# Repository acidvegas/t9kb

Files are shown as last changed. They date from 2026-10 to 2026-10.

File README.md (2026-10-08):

# T9KB

A tiny phone-style keypad for DIY projects that talks I2C. Plug it into an ESP32 *(or anything with Qwiic / I2C)* and you get the full key layout of an old desk phone handset: 3 soft keys, a 5-way d-pad, call / end / speaker / mute, and the 3x4 number pad.

There are virtually no good small modules on the market for basic I2C text input. The [M5Stack CardKB](https://docs.m5stack.com/en/unit/cardkb_1.1) is about the only one, and it is a tiny QWERTY board. Nothing like it exists for T9, so I made this one for T9 phone-style input on my own projects, starting with a DIY VoIP phone.

The layout follows the Grandstream WP826 handset. Keys are metal snap domes on gold pads, the same way real phones do it, and a 3D printed TPU key mat goes on top. A single TI TCA8418 scans the keys, so the board has no firmware to flash. The text side *(multi-tap, T9, key repeat)* lives in an Arduino library on the host.

**Status:** v0.2 hardware is designed and ready to order, not built or tested yet. The Arduino library compiles and its logic is tested on a PC, not yet on real hardware. The key mat is designed, not printed yet.

<p align="center">
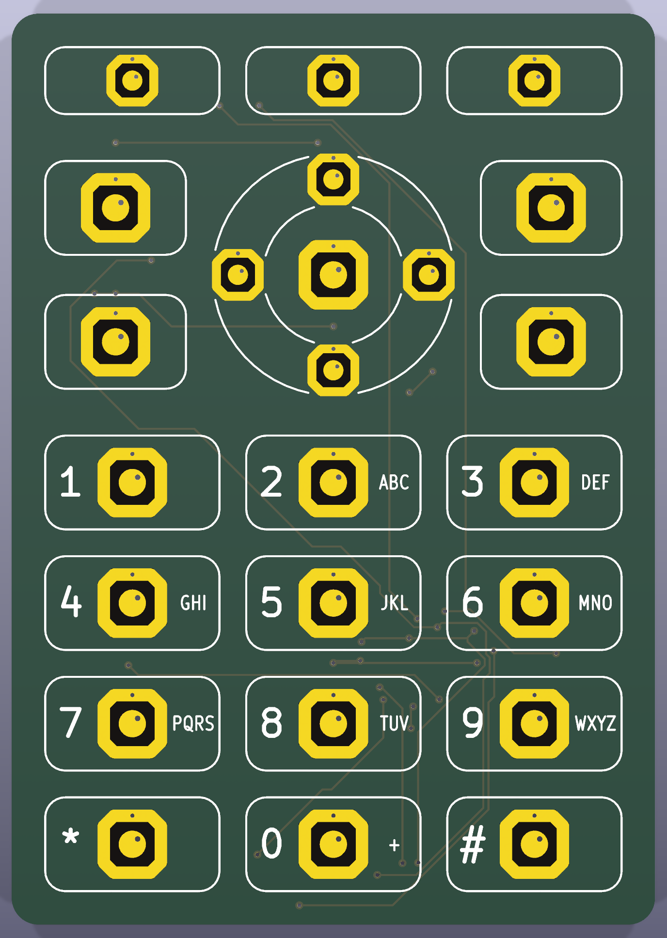
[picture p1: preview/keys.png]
Key face
  
  &nbsp;
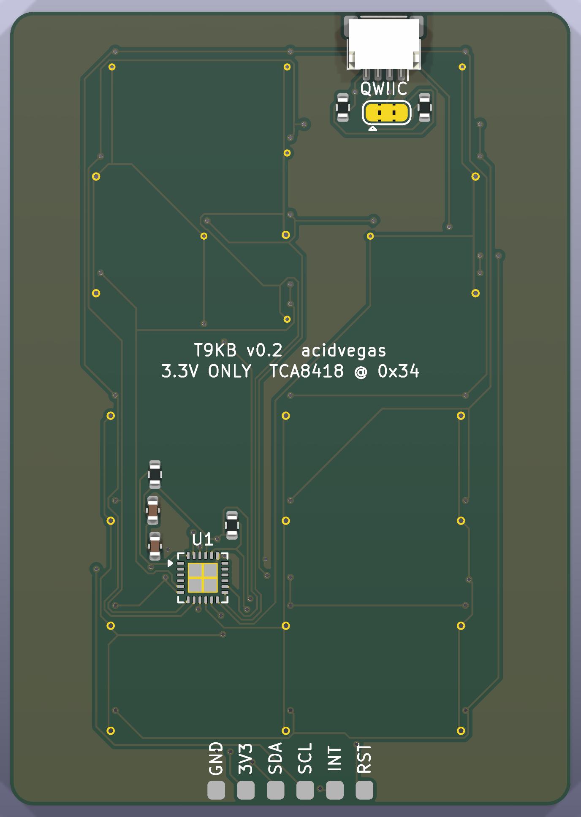
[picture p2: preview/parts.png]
Parts side
  
</p>
<p align="center">
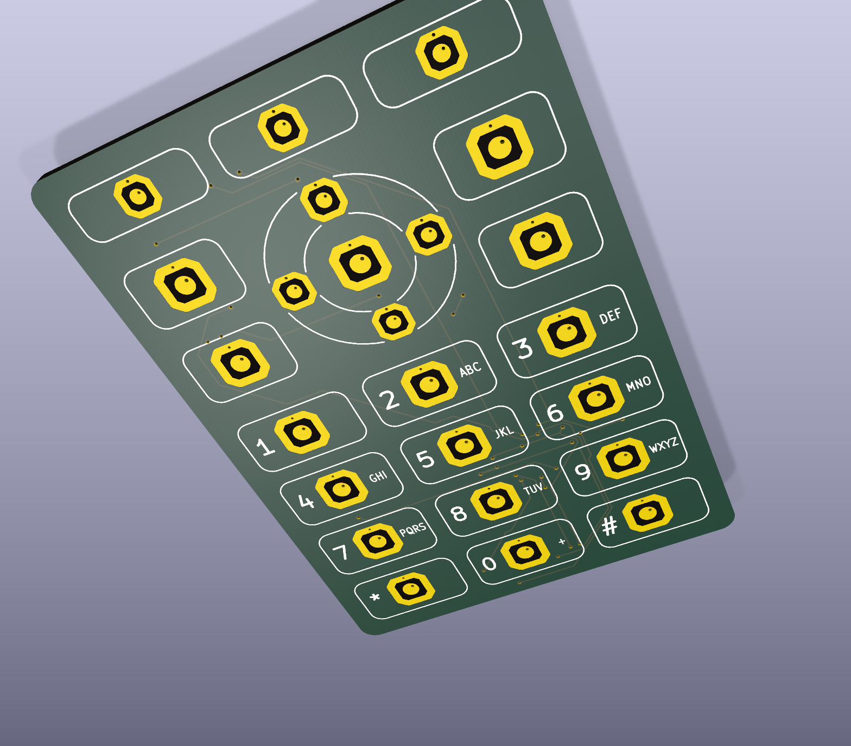
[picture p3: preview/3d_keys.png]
Key face, angled
  
  &nbsp;
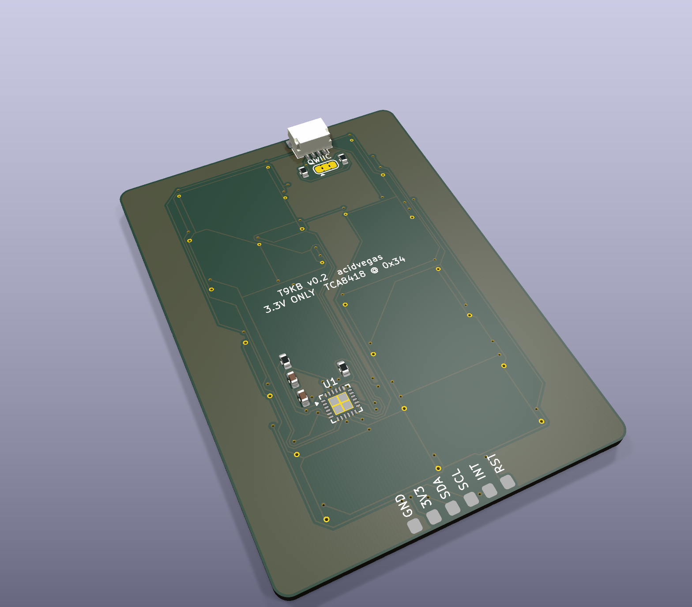
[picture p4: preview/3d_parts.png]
Parts side, angled
  
</p>

The 3D model for case and key mat design is `hardware/t9kb.step`.

## Arduino library

The library is in `library/` *(Arduino, compiles for the ESP32 core)*. Install it by copying or symlinking `library/` into your Arduino `libraries` folder as `T9KB`.

```cpp
#include <Wire.h>
#include <T9KB.h>

T9KB keypad;

void setup() {
	Wire.begin();
	keypad.begin(); // or keypad.begin(Wire, INT_GPIO, RST_GPIO) with the INT / RST pads wired
}

void loop() {
	keypad.update();
	while (keypad.available()) {
		T9Event ev = keypad.read(); // ev.key, ev.type (press / release / long / repeat), ev.code (raw key number)
	}
	uint8_t c;
	while ((c = keypad.getChar())) {
		// typed text, CardKB style
	}
}
```

Text entry through `getChar()`:

| Key | Tap in Abc / abc / ABC | Long press | 123 mode |
| --- | --- | --- | --- |
| 2 to 9 | Letters, then the digit *(abc2, def3, ... wxyz9)* | The digit  | Digit |
| 1 | `1 . , ' ? ! " -` | 1 | 1 |
| 0 | Space | 0 | 0, long press `+` |
| `*` | Symbols *(below)* | | `*` |
| `#` | `#` | Next mode  | `#`, long press mode |
| Right soft key | Backspace *(auto-repeats)* | | Backspace |
| Arrows | CardKB arrow codes *(auto-repeat)* | | Arrow codes |

The `*` symbols, in order: ``. , ' ? ! " - ( ) @ / : _ ; + % * = < > $ [ ] { } \ ~ ^ # | ` &``

- **Live preview:** each tap sends the letter right away, and the next tap on the same key sends a backspace plus the next letter. Show the text as it comes in and the screen previews every letter as you cycle. `pending()` is true while the last letter can still change, so you can underline it. The letter is final after 800 ms or when another key is pressed.
- **Modes:** long press `#` cycles Abc, abc, ABC, 123. It starts in Abc, which capitalizes the first letter and any letter after `. `, `! ` or `? `. `setMode()` changes the mode from code.
- **Codes:** backspace `0x08`, left `0xB4`, up `0xB5`, down `0xB6`, right `0xB7`, the same values the M5Stack CardKB sends. `getChar()` returns 0 when nothing is waiting.
- **Events only:** OK, call, end, the left and middle soft keys, speaker and mute type nothing. Handle them from key events.
- **Events:** read them from the queue with `available()` / `read()`, or set a callback with `onKey()`. `isPressed()` works for every key, so combos like a soft key plus a digit work.
- **Timing:** `setTapTimeout()` *(800 ms)*, `setLongPress()` *(600 ms)* and `setRepeat()` *(500 ms delay, 80 ms rate)*.
- **Reading the keypad:** without INT the library polls every 10 ms over I2C. With INT wired it only reads when a key event is waiting.

| Example | What it shows |
| --- | --- |
| `Text` | Line editor on the serial monitor with live preview and mode display |
| `Events` | Prints every key event with its raw key number |
| `Dialer` | 123 mode phone dialer using the `onKey()` callback, Call and End |
| `DeepSleep` | ESP32 deep sleep, woken by a keypress on the INT wire |

T9 word prediction is planned for later.

## Key mat

A 3D printed TPU key mat that sits on the key face: black keys with flush white legends, sized to the exact key layout. The keys stand 2.6 mm above a flat base, so the case plate can sit on the base and cover the gaps while the keys poke through. Each key is a separate island joined to the base by a thin flexible web, with a small plunger underneath that presses its dome.

<p align="center">
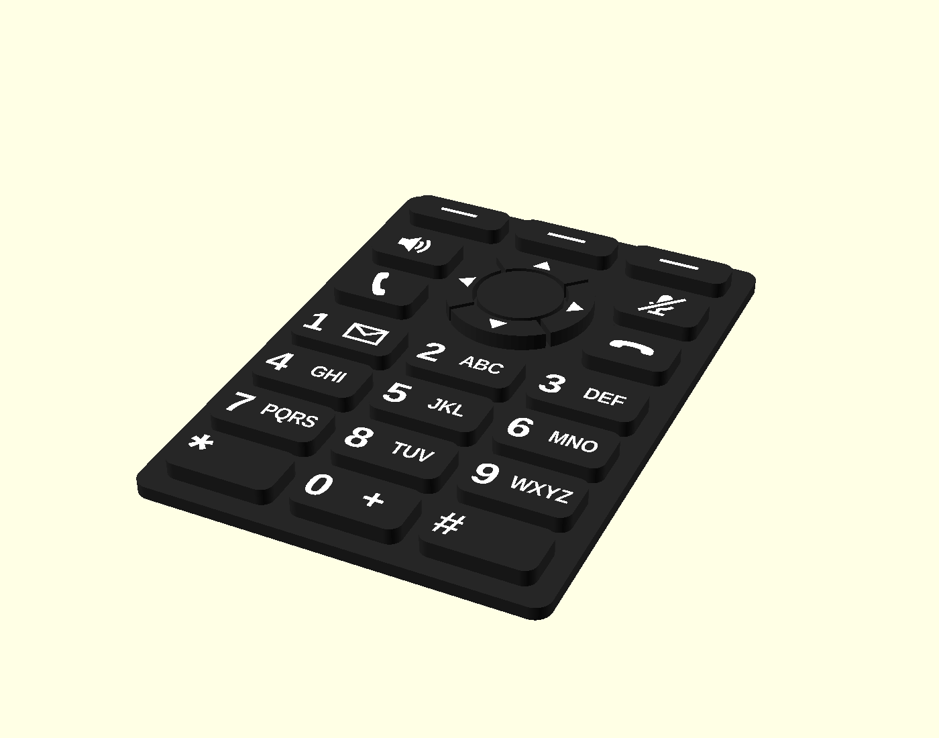
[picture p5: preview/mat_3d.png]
Key mat
  
  &nbsp;
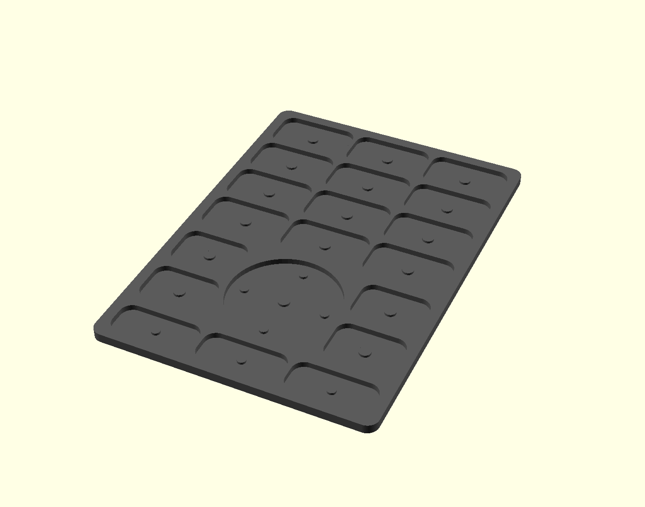
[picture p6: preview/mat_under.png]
Key mat underside
  
</p>

| File | What |
| --- | --- |
| `mat/t9kb_mat_body.stl` | Black body, already flipped face down for printing |
| `mat/t9kb_mat_legends.stl` | White legends, lined up with the body |
| `mat/t9kb_mat.scad` | OpenSCAD source with all dimensions as parameters  |

Legends: digits and letters on the number keys, an envelope *(voicemail)* on 1, speaker, muted microphone, call and hang up icons on the side keys, a line on each soft key, and arrows on the d-pad. The center select key is blank.

Printing *(Bambu A1 mini, OrcaSlicer)*:

1. Import both STLs at once and answer **yes** to loading them as a single object with multiple parts.
2. Set the body to black TPU and the legends to white TPU *(95A)*. Dry the filament first.
3. Print with 0.2 mm layers on the textured plate. The key tops print against the plate, so they come out flat and matte. Use the Arachne wall generator so the small letters *(0.3 mm strokes)* print.
4. The white is only in the first 2 layers *(0.4 mm deep)*, so every color swap happens in the first few minutes. After that the rest of the mat is black.
5. Turn on supports *(tree, on build plate only)*. Face down, the 2.5 mm border of the base hangs out past the outer keys with nothing under it. That surface ends up under the case plate, so support marks there don't show.

| Part | Size |
| --- | --- |
| Mat | 48 x 68 x 4.2 mm |
| Base | 1.6 mm thick, rests on the board; the case plate sits on it |
| Keys | Stand 2.6 mm above the base, 0.6 mm groove around each |
| Key underside | 1.0 mm above the board |
| Plungers | 2.0 mm wide on 5 mm domes, 1.5 mm on 4 mm domes |
| Legends | 0.4 mm deep, flush |

`RAISE` *(key height above the base)* in `t9kb_mat.scad` should be your case plate thickness plus how far you want the keys to stick out. The plungers stop 0.1 mm above the domes, set by `DOME_H = 0.5` *(dome height including adhesive)*. Measure your domes once they arrive. If the keys feel pre-pressed or dead, change `DOME_H` and re-export:

```
cd mat
openscad -D 'PART="body"' -D PRINT=true -o t9kb_mat_body.stl t9kb_mat.scad
openscad -D 'PART="legends"' -D PRINT=true -o t9kb_mat_legends.stl t9kb_mat.scad
```

## Case

A 3D printed two-part case: a top shell with a hole for every key and a back lid that snaps in. The mat and board drop into the top shell face down, then the lid snaps in and clamps the stack together. No screws, and the board needs no mounting holes.

<p align="center">
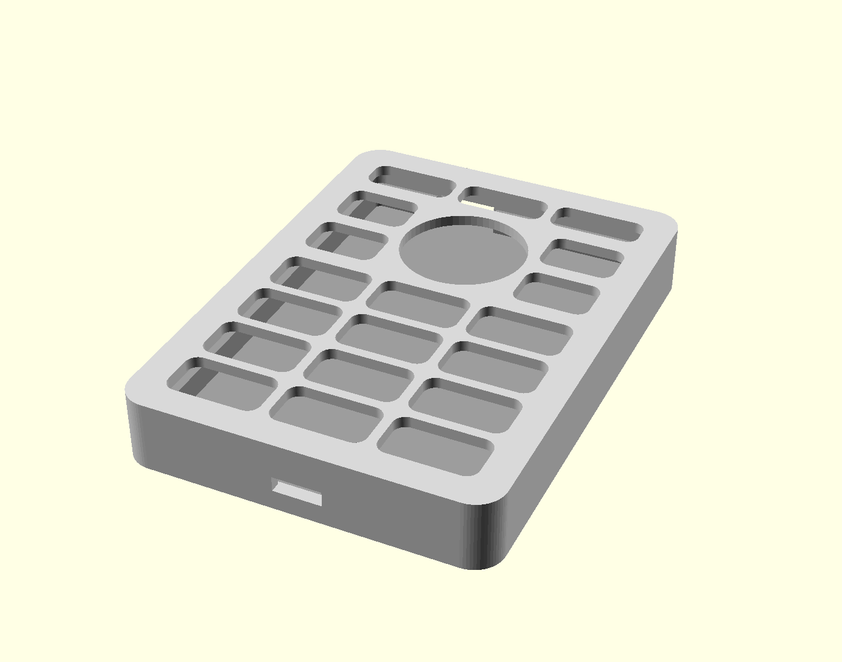
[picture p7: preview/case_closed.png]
Case
  
  &nbsp;
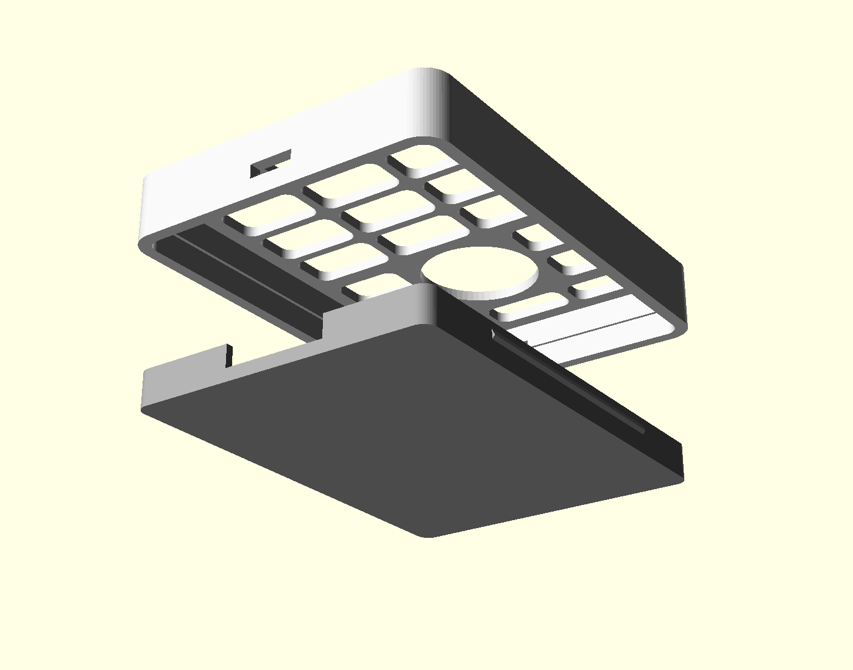
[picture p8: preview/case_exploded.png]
Case top and lid
  
</p>
<p align="center">
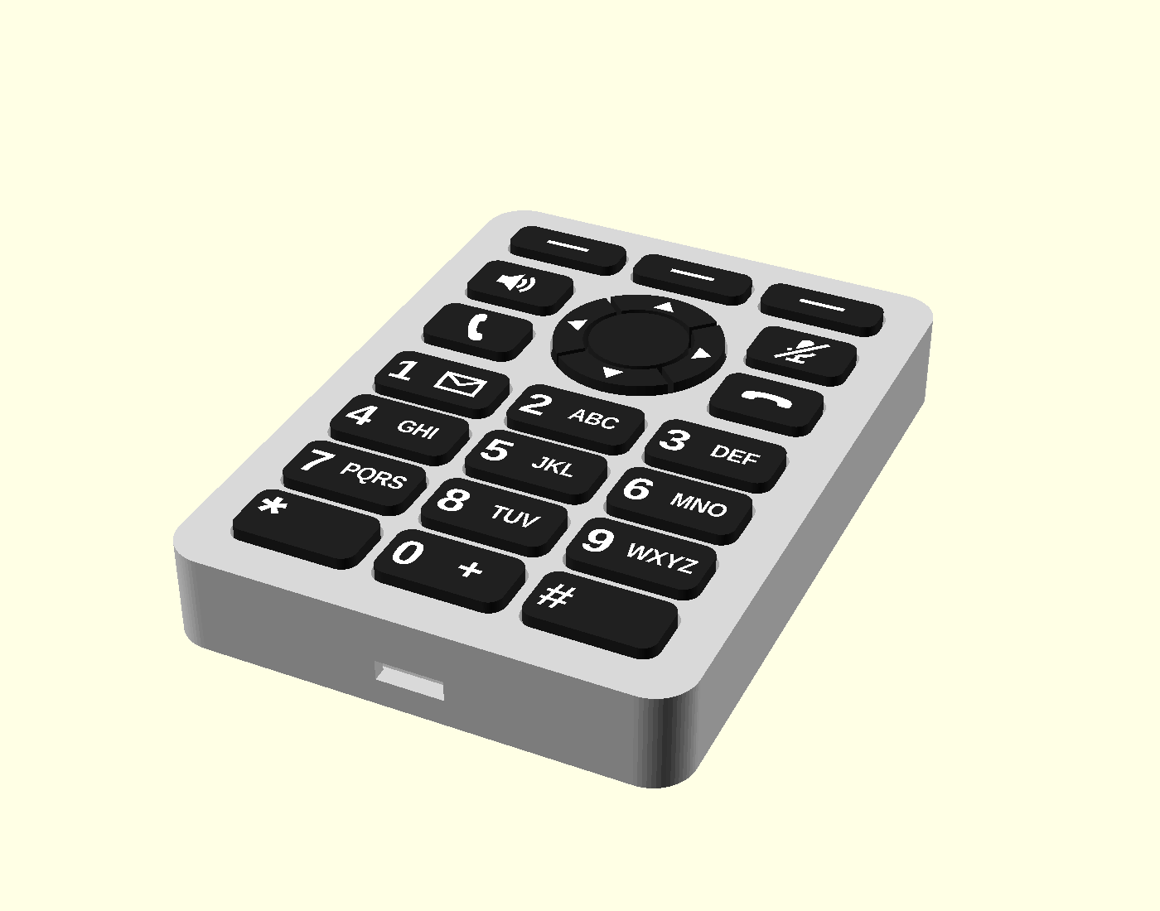
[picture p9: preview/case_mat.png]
Case with the key mat
  
</p>
<p align="center">
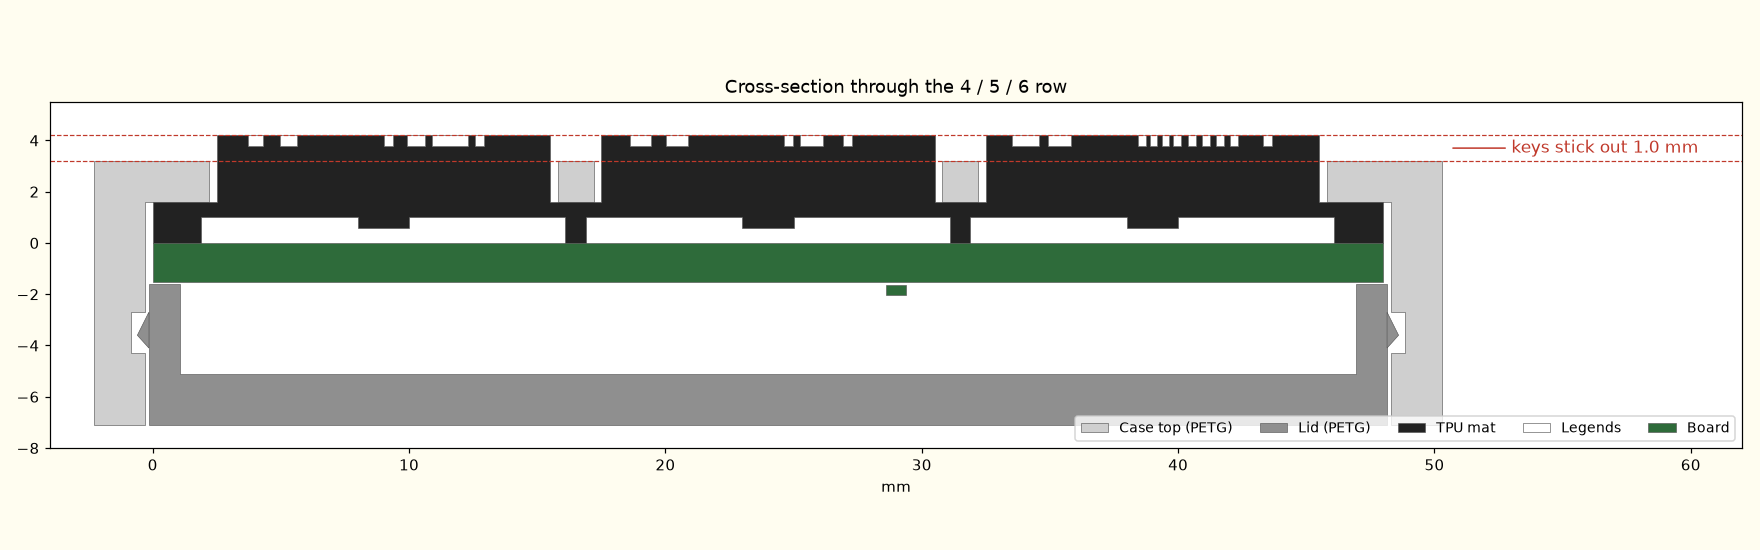
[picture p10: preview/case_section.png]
Cross-section
  
</p>

| File | What |
| --- | --- |
| `case/t9kb_case_top.stl` | Top shell, already flipped plate down for printing |
| `case/t9kb_case_lid.stl` | Back lid, floor down |
| `case/t9kb_case.scad` | OpenSCAD source with all dimensions as parameters  |

| Part | Size |
| --- | --- |
| Outside | 52.6 x 72.6 x 10.3 mm |
| Walls | 2.0 mm |
| Top plate | 1.6 mm, sits on the mat base; keys stick out 1.0 mm |
| Key holes | 0.3 mm clearance around each key, one round hole for the d-pad |
| Lid | 2.0 mm floor, 1.2 mm skirt that holds the board against the mat |
| Snap | 0.45 mm bead on each long side of the lid skirt, catches 0.3 mm in a groove |
| Openings  | Qwiic slot on the top edge, wire hole on the bottom edge for the J2 pads |
| Inside | 3.5 mm under the board for the parts *(tallest is the Qwiic jack, 2.96 mm)* |

Print both parts in PETG. It bends instead of cracking, which matters for the snap. 0.2 mm layers, 3 walls, no supports needed. The top shell prints plate down, so the face comes out flat.

Assembly:

1. Put the key mat face down into the top shell so every key sits in its hole.
2. Stick the domes on the board, then lay the board key face down onto the mat.
3. Feed any J2 wires out through the bottom hole.
4. Press the lid in from the back until both long sides click.

To open it, pry the lid out at the Qwiic slot.

## Specs

| Item | Value |
| --- | --- |
| Board size  | 48 x 68 mm, 1.6 mm thick, 2 layers, 2 mm corner radius |
| Keys | 24 metal dome pads *(Snaptron patterns: 17 for 5 / 5.3 mm domes, 7 for 4 mm domes)* |
| Controller  | TI TCA8418 keypad scanner, no firmware |
| I2C address | 0x34 *(fixed)* |
| Power | 3.3 V only *(1.65 to 3.6 V)* |
| Connector | Qwiic / STEMMA QT *(JST SH 4-pin)*, top edge, parts side |
| Key face | Flat: gold dome pads and legends only *(KiCad bottom layer)* |
| Parts side  | All parts *(8 total, KiCad top layer)* |

## Key layout

All sizes in mm, measured on the key face. The key area is 43 x 63, centered on the board with a 2.5 border on every side.

| Keys | Count | Size | Dome |
| --- | ----- | --- | ---- |
| Soft keys | 3 | 13 x 5 | 4 mm |
| D-pad ring | | 18 circle | |
| D-pad center | 1 | 10.5 circle | 5 mm |
| D-pad arrows | 4 | In the ring around the center | 4 mm |
| Side keys | 4 | 10.5 x 7, two on each side | 5 mm |
| Number keys  | 12 | 13 x 7 | 5 mm |

| Gap | Size |
| --- | ---- |
| Between soft keys, between number keys | 2 |
| Soft keys to d-pad | 3 |
| Soft keys to side keys | 3.5  |
| Between the 2 stacked side keys | 3 |
| D-pad to number keys | 3 |
| Side keys to number keys | 3.5  |

The outer edges of the soft keys, side keys and number keys all line up.

## Connections

Qwiic connector *(J1)*:

| Pin | Signal |
| --- | --- |
| 1 | GND |
| 2 | 3.3V |
| 3 | SDA |
| 4 | SCL |

Breakout pads on the bottom edge of the parts side *(J2, 2.54 mm pitch, solder wires or an SMD header)*:

| Pad | Signal | Notes |
| --- | --- | --- |
| 1 | GND | |
| 2 | 3V3 | |
| 3 | SDA | |
| 4 | SCL | |
| 5 | INT | Goes low when a key event is waiting *(10k pull-up on board)* |
| 6 | RST | Pull low to reset the TCA8418 *(10k pull-up on board)* |

Qwiic has no spare wire for INT. Over Qwiic alone the host polls the keypad; solder a wire from J2's INT pad to a GPIO for interrupt-driven reads and wake-on-keypress.

The board has 4.7k I2C pull-ups through the 3-pad solder jumper JP1. It comes bridged. If you chain it with other boards that already have pull-ups, cut both copper bars on JP1.

## Key map

The TCA8418 reports a key number from 1 to 80 *(`row * 10 + column + 1`)*. Bit 7 of the event byte is 1 for press, 0 for release.

| Key | Row | Col | Key number |
| --- | --- | --- | --- |
| 1 | 0 | 0 | 1 |
| 2 | 0 | 1 | 2 |
| 3 | 0 | 2 | 3 |
| Soft left | 0 | 3 | 4 |
| Soft middle | 0 | 4 | 5 |
| Soft right  | 0 | 5 | 6 |
| 4 | 1 | 0 | 11 |
| 5 | 1 | 1 | 12 |
| 6 | 1 | 2 | 13 |
| Speaker | 1 | 3 | 14 |
| Up | 1 | 4 | 15 |
| Mute | 1 | 5 | 16 |
| 7 | 2 | 0 | 21 |
| 8 | 2 | 1 | 22 |
| 9 | 2 | 2 | 23 |
| Left | 2 | 3 | 24 |
| OK | 2 | 4 | 25 |
| Right | 2 | 5 | 26 |
| * | 3 | 0 | 31 |
| 0 | 3 | 1 | 32 |
| # | 3 | 2 | 33 |
| Call | 3 | 3 | 34 |
| Down | 3 | 4 | 35 |
| End | 3 | 5 | 36 |

Minimum setup over I2C:

| Register | Name | Write | Why |
| --- | --- | ----- | --- |
| 0x1D | KP_GPIO1 | 0x0F  | Rows 0 to 3 are keypad rows |
| 0x1E | KP_GPIO2 | 0x3F  | Columns 0 to 5 are keypad columns |
| 0x01 | CFG | 0x01  | Interrupt on key events |

Then read `KEY_LCK_EC` *(0x03)* for the event count, read `KEY_EVENT_A` *(0x04)* once per event, and write 0x01 to `INT_STAT` *(0x02)* to clear the interrupt.

The board has no diodes, so single keys and 2-key combos are reliable. Pressing 3 keys that form an L in the matrix can show a fake 4th key.

## Parts

Assembled by JLCPCB *(all on the parts side)*:

| Ref | Part | Package | LCSC | JLC type |
| --- | --- | --- | --- | --- |
| U1 | TCA8418RTWR | WQFN-24 4x4 mm  | C138713 | Extended |
| J1 | JST SM04B-SRSS-TB *(Qwiic)* | SMD right angle | C160404 | Extended |
| C1 | 100 nF | 0603 | C14663  | Basic |
| C2 | 10 uF | 0603 | C19702  | Basic |
| R1, R2 | 4.7k *(I2C pull-ups)* | 0603 | C23162  | Basic |
| R3, R4 | 10k *(RST, INT pull-ups)* | 0603 | C25804  | Basic |

Bought separately and added by hand:

| Qty | Part | Where | Notes |
| --- | --- | --- | --- |
| 20  | 5 to 5.3 mm metal domes *(see Dome sources)* | Varies | 17 needed, rest are spares |
| 10  | 4 mm metal domes *(see Dome sources)* | Varies | 7 needed, rest are spares  |
| 1 | Kapton *(polyimide)* tape | Anywhere | Only for loose domes |

## Dome sources

The pads follow Snaptron's published single-sided contact patterns: 17 pads for 5 / 5.3 mm domes and 7 pads for 4 mm domes *(soft keys and d-pad arrows)*. Prices and stock were checked on 2026-10-07.

Recommended, exact match for the pad patterns with a known force:

| Pads | Part | Source | Force | Price | Notes |
| ---- | --- | --- | --- | --- | --- |
| 5 mm | Snaptron GX05170 *(5.3 mm four-leg)* | [DigiKey 4955-GX05170-ND](https://www.digikey.com/en/products/detail/snaptron/GX05170/20376517) | 170 g ±30 g | $36.37 for 100 | Loose, needs tape |
| 4 mm | Snaptron GX04200 *(4.0 mm four-leg)* | [DigiKey 4955-GX04200-ND](https://www.digikey.com/en/products/detail/snaptron/GX04200/20376515) | 200 g ±30 g | $37.99 for 100 | Loose, needs tape |
| Tape | 1" polyimide *(Kapton style)* tape | [Amazon B006ZFNB2I](https://www.amazon.com/Mil-Kapton-Tape-Polyimide-yds/dp/B006ZFNB2I) | | | |

Cheaper, peel-and-stick, from [ButtonWorx](https://buttonworx.com) *(Maine, US, $4 minimum order, no force listed)*:

| Pads | Part | Price | Fit |
| ---- | --- | --- | --- |
| 5 mm | [Snap Dome Round 5mm Dimple, Peel and Stick option](https://buttonworx.com/metal-domes/285-snap-dome-round-5mmD.html) | $0.80 each | Whole rim on the frame |
| 5 mm | [Snap Dome Chopped Circle 5.2mm Peel & Stick](https://buttonworx.com/metal-domes/291-snap-dome-cut-circle-5-2x3-8.html) | $0.50 each | Fits |
| 4 mm | [Snap Dome Round 4mm Dimple, Peel and Stick option](https://buttonworx.com/metal-domes/284-snap-dome-round-4mmD.html) | $0.80 each | Marginal: rim rests on the frame corners only, no size tolerance given |

The adhesive squares around neighboring d-pad domes may overlap; trim them if they do. A 4.5 mm dome does not fit the 4 mm pads.

## Ordering from JLCPCB

Upload `hardware/fab/t9kb_gerbers.zip` and use these settings:

| Setting | Value |
| --- | --- |
| Layers | 2 |
| Dimensions | 48 x 68 mm *(auto-detected)* |
| Material | FR-4 |
| PCB thickness  | 1.6 mm *(Economic PCBA only offers ENIG at 1.6 mm)* |
| Surface finish | ENIG *(required, the dome contacts need gold)* |
| Gold thickness | 2U" *(1U" also works)* |
| PCB assembly | Yes, Economic |
| Assembly side  | Top side |
| BOM / CPL | `hardware/fab/BOM.csv` and `hardware/fab/CPL.csv` |

On the placement preview page, check these before paying:

- **U1:** the dot on the chip lines up with the pin 1 triangle printed on the board.
- **J1:** the connector opening faces the top edge of the board.

If either is turned wrong, rotate it right there in the preview. Resistors and capacitors do not care.

## Assembly

1. Clean the key face with isopropyl alcohol.
2. Place a dome on each gold pad, centered on the round contact *(not on the small hole, which is off-center on purpose)*. The small pads *(soft keys and d-pad arrows)* take 4 mm domes, the rest take 5 mm domes. Four-leg domes go with a leg on each of the 4 cut corners of the gold frame.
3. Tape over the domes with Kapton tape, or use peel-and-stick domes. Air vents through the small hole in each center pad, so the tape can cover the domes fully.
4. Test by pressing each dome with a finger while reading key events.

A dome that sits crooked can be peeled off and placed again. Nothing on the key face is soldered.

## Rebuilding the board

The board is generated by script *(KiCad 9)*. There is no schematic; the netlist lives in `gen_pcb.py`.

```
cd hardware
./autoroute.sh    # place parts, autoroute with freerouting, pour ground, run DRC
python3 fab.py    # gerbers, drill files, BOM, CPL
```

`autoroute.sh` expects `freerouting.jar` in `tools/`. Download it from the [freerouting v2.0.1 release](https://github.com/freerouting/freerouting/releases/tag/v2.0.1) *(needs Java 21)*.

## References

- `ref/tca8418.pdf`: [TI TCA8418 datasheet](https://www.ti.com/lit/ds/symlink/tca8418.pdf)
- `ref/snaptron_guide.pdf`: Snaptron metal dome design guide *(contact pad patterns, plating, venting)*

## Notes

- The TCA8418 exposed pad is tied to ground, as TI recommends *(ground or floating, never power)*.
- Dome pads follow Snaptron's single-sided contact patterns for 5 / 5.3 mm and 4 mm domes, with the off-center via-in-pad option for 2-layer boards. There is no solder mask inside the pad area, per Snaptron.
- U1 uses TI's own land pattern and stencil for the RTW0024B package *(TCA8418 datasheet)*.
- The key face is the KiCad bottom layer so JLC assembles the top side.
- LEDs and backlight were removed for this revision. They may come back later.

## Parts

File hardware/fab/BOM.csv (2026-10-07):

Comment | Designator | Footprint | LCSC
100nF | C1 | C_0603_1608Metric | C14663
10k | R3,R4 | R_0603_1608Metric | C25804
10uF | C2 | C_0603_1608Metric | C19702
4.7k | R1,R2 | R_0603_1608Metric | C23162
Qwiic | J1 | JST_SH_SM04B-SRSS-TB_1x04-1MP_P1.00mm_Horizontal | C160404
TCA8418RTWR | U1 | WQFN-24-1EP_4x4mm_P0.5mm_EP2.45mm_TI_RTW0024B | C138713

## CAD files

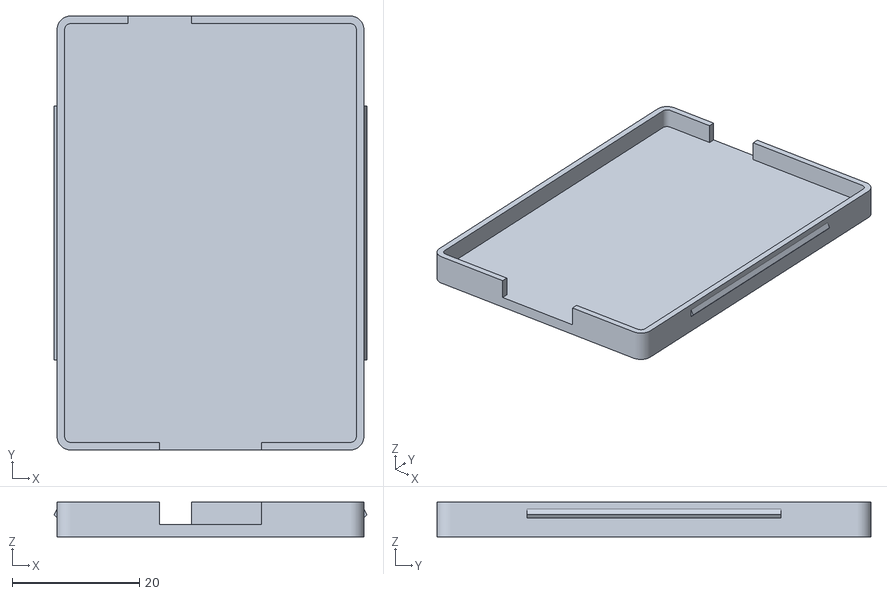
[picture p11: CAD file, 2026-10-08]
case/t9kb_case_lid.stl
49.2 x 68.3 x 5.50

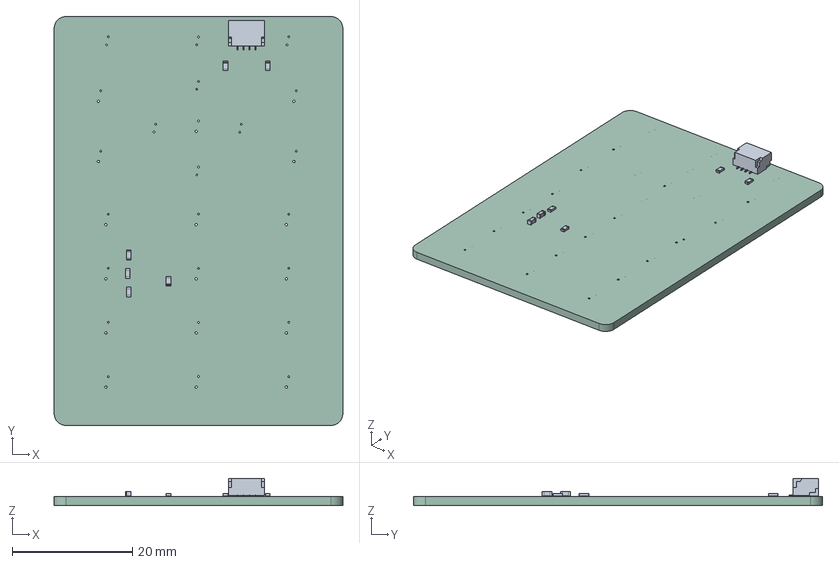
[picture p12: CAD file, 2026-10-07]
hardware/t9kb.step
48.0 x 68.0 x 4.55 mm
C_0603_1608Metric x 2
R_0603_1608Metric x 4
JST_SH_SM04B-SRSS-TB_1x04-1MP_P1.00mm_Horizontal
t9_keypad_back_PCB

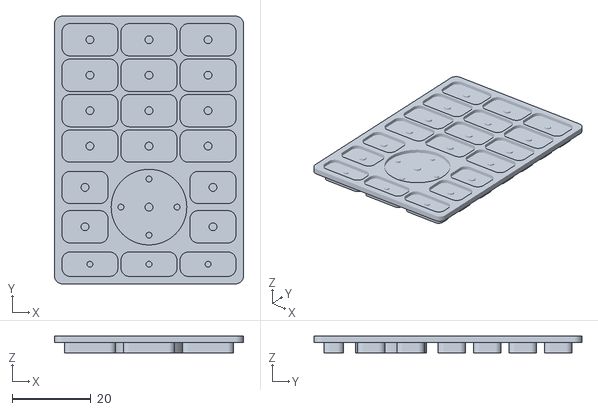
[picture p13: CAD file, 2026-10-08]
mat/t9kb_mat_body.stl
48.0 x 68.0 x 4.20

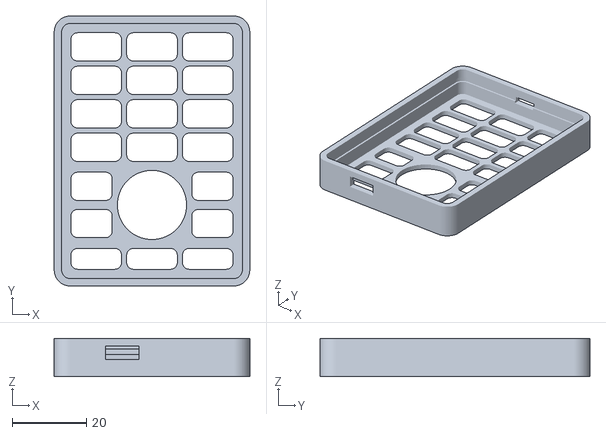
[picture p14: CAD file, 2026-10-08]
case/t9kb_case_top.stl
52.6 x 72.6 x 10.3

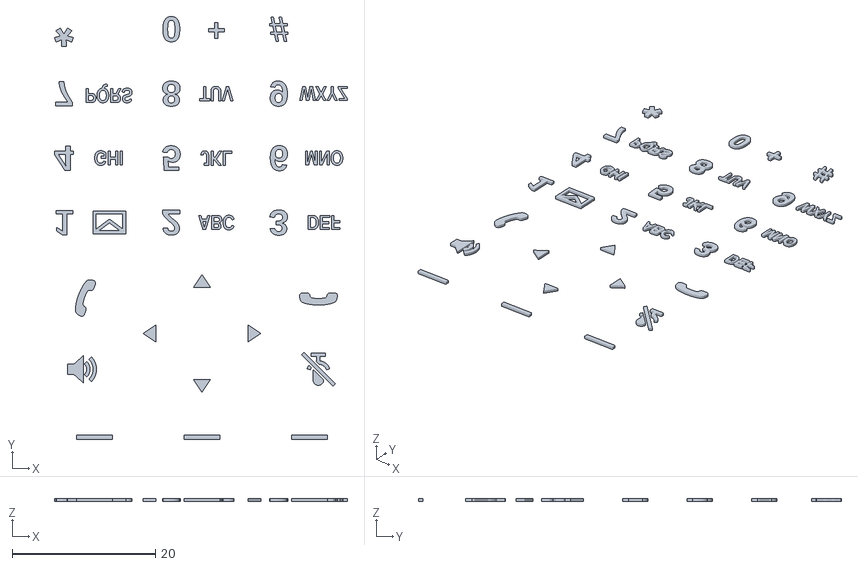
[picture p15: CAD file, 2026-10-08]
mat/t9kb_mat_legends.stl
40.9 x 59.0 x 0.4

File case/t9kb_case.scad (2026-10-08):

// T9KB case: top shell with key cutouts + snap-in back lid. PETG recommended.
// The board and key mat drop into the top shell face down, then the lid snaps in and clamps them.
// Coordinates follow the board's key face: x right, y down from the top left corner, z = 0 at the key face.
// Export: openscad -D 'PART="top"' / "lid", PRINT=true lays each part flat for printing.

use <../mat/t9kb_mat.scad>

PART  = "case";  // top, lid, case (both, closed)
PRINT = false;

W = 48;          // board
H = 68;
R = 2;

CLR    = 0.3;    // board / mat to wall
WALL   = 2.0;    // side walls
PLATE  = 1.6;    // top plate over the mat base
MAT    = 1.6;    // mat base thickness (mat BEZEL)
KEYCLR = 0.3;    // key cutout clearance
PCB    = 1.6;
BACK   = 3.5;    // room under the board for the parts (tallest is the Qwiic jack, 2.96 mm)
FLOOR  = 2.0;    // lid thickness
LIDCLR = 0.15;   // lid to wall
SKIRT  = 1.2;    // lid skirt thickness, also the ledge the board rests on
BEAD   = 0.45;   // snap bead on the lid skirt, catches 0.3 mm past the 0.15 mm lid gap
BEAD_Z = -3.6;   // snap height

Z_TOP   = MAT + PLATE;             // 3.2
Z_BOARD = -PCB;                    // -1.6, parts side of the board
Z_IN    = Z_BOARD - BACK;          // -5.1, top of the lid
Z_BOT   = Z_IN - FLOOR;            // -7.1

QWIIC_X = 16;    // Qwiic jack center on the top edge (key face x)
WIRE_X  = 24;    // breakout pads center on the bottom edge

$fn = 64;

module board2d(d = 0) {
	offset(R + d) offset(-R) square([W, H]);
}

module ring(d0, d1) {
	difference() {
		board2d(d1);
		board2d(d0);
	}
}

// key-face y to OpenSCAD y
function Y(y) = H - y;

module bead(len) {
	// lead-in on top (the lid goes in from below), steeper retaining face underneath
	rotate([90, 0, 0]) linear_extrude(len, center = true) polygon([[0, -0.5], [BEAD, 0], [0, 0.9]]);
}

module top() {
	difference() {
		union() {
			// plate
			translate([0, 0, MAT]) linear_extrude(PLATE) board2d(CLR + WALL);
			// walls
			translate([0, 0, Z_BOT]) linear_extrude(Z_TOP - Z_BOT) ring(CLR, CLR + WALL);
		}
		// key holes
		translate([0, 0, MAT - 0.01]) linear_extrude(PLATE + 0.02) keys2d(KEYCLR);
		// snap groove for the lid bead
		translate([0, 0, BEAD_Z - 0.7]) linear_extrude(1.6) ring(CLR - 0.01, CLR + BEAD + 0.1);
		// Qwiic slot
		translate([QWIIC_X - 4.5, H - 0.5, Z_BOARD - 3.4]) cube([9, CLR + WALL + 1.5, 3.6]);
		// wire hole
		translate([WIRE_X - 3.5, -CLR - WALL - 1, Z_BOARD - 2.6]) cube([7, CLR + WALL + 1.5, 2.2]);
	}
}

module lid() {
	difference() {
		union() {
			translate([0, 0, Z_BOT]) linear_extrude(FLOOR) board2d(CLR - LIDCLR);
			// skirt: rises to the board and holds it against the mat
			translate([0, 0, Z_IN - 0.01]) linear_extrude(BACK + 0.01) ring(CLR - LIDCLR - SKIRT, CLR - LIDCLR);
			// snap beads on the long sides, clear of the corners
			for (x = [-CLR + LIDCLR, W + CLR - LIDCLR]) translate([x, H / 2, BEAD_Z]) rotate([0, 0, x < W / 2 ? 180 : 0]) bead(40);
		}
		// clear the Qwiic jack and its plug
		translate([QWIIC_X - 5, Y(5), Z_IN]) cube([10, 10, BACK + 1]);
		// clear the breakout pads and their wires
		translate([WIRE_X - 8, Y(H + 5), Z_IN]) cube([16, 7, BACK + 1]);
	}
}

if (PART == "top") {
	if (PRINT) translate([0, H, Z_TOP]) rotate([180, 0, 0]) top();
	else color("#d0d0d0") top();
}
if (PART == "lid") {
	if (PRINT) translate([0, 0, -Z_BOT]) lid();
	else color("#9a9a9a") lid();
}
if (PART == "case") {
	color("#d0d0d0") top();
	color("#9a9a9a") lid();
}

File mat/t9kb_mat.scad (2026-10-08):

// T9KB TPU key mat: black body with flush white legends, sized to the T9KB board (48 x 68 mm).
// Coordinates follow the board's key face: x right, y down from the top left corner.
// Export: openscad -D 'PART="body"' / "legends" / "both", PRINT=true flips it face down for printing.

PART  = "both";  // body, legends, both (preview)
PRINT = false;   // true: key tops on the bed, for the print files

W = 48;          // board size
H = 68;
R = 2;           // board corner radius

BEZEL  = 1.6;    // flat part between the keys, rests on the board; the case plate sits on it
RAISE  = 2.6;    // how far the keys stand above the flat part: case plate 1.6 + 1.0 sticking out
Z0     = 1.0;    // underside of the keys above the board
WEB    = 0.6;    // flexible web joining each key to the flat part
GROOVE = 0.6;    // gap around each key
LEGEND = 0.4;    // legend depth, 2 layers at 0.2 mm

DOME_H = 0.5;    // dome height on the board incl. adhesive, measure yours
GAP    = 0.1;    // plunger clearance above the dome

KEY_R = 1.5;     // key corner radius
TOP   = BEZEL + RAISE;

DIGIT  = "Liberation Sans:style=Bold";
LETTER = "Liberation Sans Narrow:style=Bold";
ICONS  = "FreeSerif";

// x, y, w, h, legend, sublegend, dome size. Legends starting with @ are icons.
KEYS = [
	[9,     5,    13,   5, "@soft",    "",      4],
	[24,    5,    13,   5, "@soft",    "",      4],
	[39,    5,    13,   5, "@soft",    "",      4],
	[7.75,  14.5, 10.5, 7, "@speaker", "",      5],
	[40.25, 14.5, 10.5, 7, "@mute",    "",      5],
	[7.75,  24.5, 10.5, 7, "@call",    "",      5],
	[40.25, 24.5, 10.5, 7, "@end",     "",      5],
	[9,  35, 13, 7, "1", "@mail", 5], [24, 35, 13, 7, "2", "ABC", 5], [39, 35, 13, 7, "3", "DEF",  5],
	[9,  44, 13, 7, "4", "GHI",   5], [24, 44, 13, 7, "5", "JKL", 5], [39, 44, 13, 7, "6", "MNO",  5],
	[9,  53, 13, 7, "7", "PQRS",  5], [24, 53, 13, 7, "8", "TUV", 5], [39, 53, 13, 7, "9", "WXYZ", 5],
	[9,  62, 13, 7, "*", "",      5], [24, 62, 13, 7, "0", "+",   5], [39, 62, 13, 7, "#", "",     5],
];

// d-pad: 18 mm ring, 10.5 mm round center, arrow domes centered in the ring
DX = 24;
DY = 19.5;
DR = 9;
DC = 5.25;
DA = (DC + DR) / 2;

$fn = 64;

function Y(y) = H - y;

module rrect(cx, cy, w, h, r) {
	translate([cx, Y(cy)]) offset(r) square([w - 2 * r, h - 2 * r], center = true);
}

module outline() {
	offset(R) offset(-R) square([W, H]);
}

// every key shape, grown by d
module keys2d(d = 0) {
	for (k = KEYS) offset(d) rrect(k[0], k[1], k[2], k[3], KEY_R);
	translate([DX, Y(DY)]) circle(DR + d);
}

// the separate moving parts: rectangle keys, d-pad center, 4 arrows
module islands2d() {
	for (k = KEYS) rrect(k[0], k[1], k[2], k[3], KEY_R);
	translate([DX, Y(DY)]) {
		circle(DC);
		difference() {
			circle(DR);
			circle(DC + GROOVE);
			for (a = [45, 135]) rotate(a) square([2 * DR + 2, GROOVE], center = true);
		}
	}
}

// dome centers and plunger diameters
DOMES = concat(
	[for (k = KEYS) [k[0], k[1], k[6] == 5 ? 2.0 : 1.5]],
	[[DX, DY, 2.0]],
	[for (a = [0, 90, 180, 270]) [DX + DA * cos(a), DY - DA * sin(a), 1.5]]
);

// --- icons, about 5 mm, strokes 0.45 mm or more for a 0.4 mm nozzle ---

module arc2d(r1, r2, a0, a1) {
	polygon(concat([for (a = [a0:5:a1]) r2 * [cos(a), sin(a)]], [for (a = [a1:-5:a0]) r1 * [cos(a), sin(a)]]));
}

module bar(p1, p2, w = 0.5) {
	hull() {
		translate(p1) circle(d = w, $fn = 16);
		translate(p2) circle(d = w, $fn = 16);
	}
}

module speaker() {
	translate([-0.9, 0]) {
		translate([-1.6, -0.75]) square([0.9, 1.5]);
		polygon([[-0.7, -0.75], [0.6, -1.9], [0.6, 1.9], [-0.7, 0.75]]);
		arc2d(1.05, 1.55, -45, 45);
		arc2d(1.95, 2.45, -45, 45);
	}
}

module mic() {
	hull() {
		translate([0, 1.5]) circle(0.75);
		translate([0, 0.3]) circle(0.75);
	}
	translate([0, 0.5]) arc2d(1.2, 1.7, 200, 340);
	translate([-0.25, -1.9]) square([0.5, 0.8]);
	translate([-1.0, -2.3]) square([2.0, 0.5]);
}

module mute() {
	difference() {
		mic();
		rotate(-45) square([1.1, 7], center = true);
	}
	rotate(-45) square([0.5, 6.2], center = true);
}

module handset() {
	offset(0.12) text("\U01F4DE", 5.6, ICONS, halign = "center", valign = "center");
}

module mail() {
	difference() {
		square([4.6, 3.2], center = true);
		square([3.7, 2.3], center = true);
	}
	bar([-2.0, 1.3], [0, -0.2], 0.45);
	bar([2.0, 1.3], [0, -0.2], 0.45);
}

module icon(name) {
	if (name == "@soft") square([5, 0.6], center = true);
	else if (name == "@speaker") speaker();
	else if (name == "@mute") mute();
	else if (name == "@call") handset();
	else if (name == "@end") rotate(-110) handset();
	else if (name == "@mail") mail();
}

module legends2d() {
	for (k = KEYS) translate([k[0], Y(k[1])]) {
		if (k[4][0] == "@") icon(k[4]);
		else translate([-4.3, 0]) text(k[4], k[4] == "*" ? 5 : 3.6, DIGIT, halign = "center", valign = "center");
		if (k[5] == "@mail") translate([2.1, 0]) icon(k[5]);
		else if (k[5] == "+") translate([2.0, 0]) text(k[5], 3.2, DIGIT, halign = "center", valign = "center");
		else if (k[5] != "") translate([2.0, 0]) text(k[5], 2.1, LETTER, halign = "center", valign = "center");
	}
	// arrows; the center select key has no legend
	translate([DX, Y(DY)]) for (a = [0, 90, 180, 270]) rotate(a) translate([DA, 0]) polygon([[1.1, 0], [-0.7, 1.2], [-0.7, -1.2]]);
}

module legends() {
	translate([0, 0, TOP - LEGEND]) linear_extrude(LEGEND) intersection() {
		legends2d();
		islands2d();
	}
}

module body() {
	difference() {
		union() {
			// flat part between the keys
			linear_extrude(BEZEL) difference() {
				outline();
				keys2d(GROOVE);
			}
			// keys
			translate([0, 0, Z0]) linear_extrude(TOP - Z0) islands2d();
			// web across the grooves, level with the key undersides
			translate([0, 0, Z0]) linear_extrude(WEB) difference() {
				keys2d(GROOVE);
				islands2d();
			}
			// plungers
			for (d = DOMES) translate([d[0], Y(d[1]), DOME_H + GAP]) cylinder(d = d[2], h = Z0 - DOME_H - GAP + 0.01);
		}
		legends();
	}
}

module part() {
	if (PART == "body" || PART == "both") color("#303030") body();
	if (PART == "legends" || PART == "both") color("white") translate([0, 0, PART == "both" ? 0.01 : 0]) legends(); // lifted in previews to avoid z-fighting
}

if (PRINT) translate([0, H, TOP]) rotate([180, 0, 0]) part();
else part();

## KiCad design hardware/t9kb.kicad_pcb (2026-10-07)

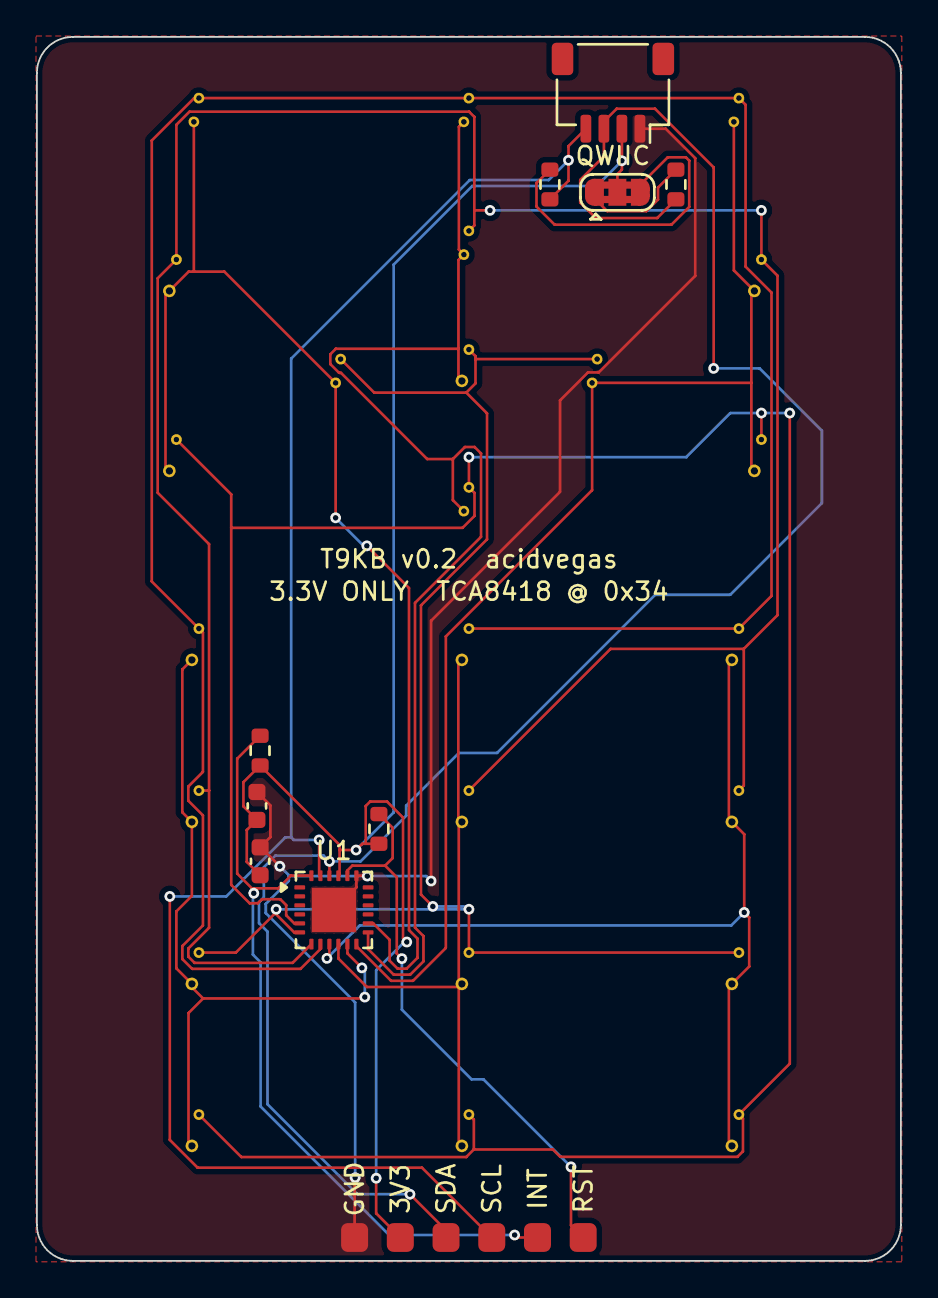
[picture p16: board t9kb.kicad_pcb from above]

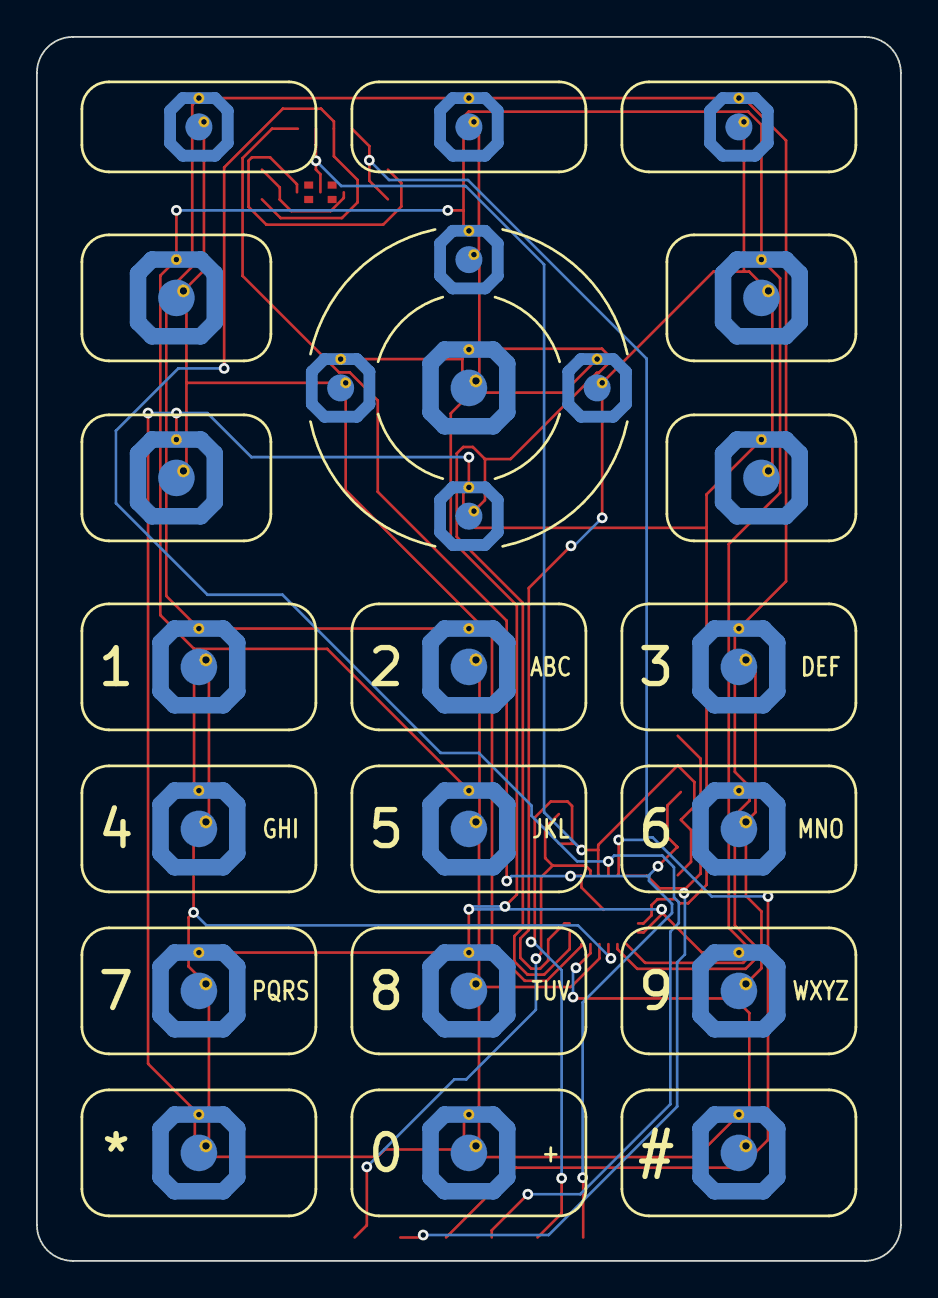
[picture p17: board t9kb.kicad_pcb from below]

Board: 2 copper layers, 48.0 x 68.0 mm, 34 parts (24 on the bottom side), 18 nets.

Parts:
C1: 100nF; C_0603_1608Metric
C2: 10uF; C_0603_1608Metric
J1: Qwiic; JST_SH_SM04B-SRSS-TB_1x04-1MP_P1.00mm_Horizontal
J2: Breakout; Pads_1x06_P2.54mm_SMD
JP1: I2C_PU; SolderJumper-3_P1.3mm_Bridged2Bar123_RoundedPad1.0x1.5mm
R1, R2: 4.7k; R_0603_1608Metric
R3, R4: 10k; R_0603_1608Metric
SW1: SOFT_L; MetalDome_4mm
SW2: SOFT_M; MetalDome_4mm
SW3: SOFT_R; MetalDome_4mm
SW4: SPK; MetalDome_5mm
SW5: UP; MetalDome_4mm
SW6: CONTACT; MetalDome_5mm
SW7: LEFT; MetalDome_4mm
SW8: OK; MetalDome_5mm
SW9: RIGHT; MetalDome_4mm
SW10: CALL; MetalDome_5mm
SW11: DOWN; MetalDome_4mm
SW12: END; MetalDome_5mm
SW13: K1; MetalDome_5mm
SW14: K2; MetalDome_5mm
SW15: K3; MetalDome_5mm
SW16: K4; MetalDome_5mm
SW17: K5; MetalDome_5mm
SW18: K6; MetalDome_5mm
SW19: K7; MetalDome_5mm
SW20: K8; MetalDome_5mm
SW21: K9; MetalDome_5mm
SW22: KSTAR; MetalDome_5mm
SW23: K0; MetalDome_5mm
SW24: KHASH; MetalDome_5mm
U1: TCA8418RTWR; WQFN-24-1EP_4x4mm_P0.5mm_EP2.45mm_TI_RTW0024B

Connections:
+3V3: C1.1, C2.1, J1.2, J2.2, JP1.2, R3.1, R4.1, U1.21
COL0: SW13.1, SW16.1, SW19.1, SW22.1, U1.9
COL1: SW14.1, SW17.1, SW20.1, SW23.1, U1.10
COL2: SW15.1, SW18.1, SW21.1, SW24.1, U1.11
COL3: SW1.1, SW4.1, SW7.1, SW10.1, U1.12
COL4: SW2.1, SW5.1, SW8.1, SW11.1, U1.13
COL5: SW3.1, SW6.1, SW9.1, SW12.1, U1.14
GND: C1.2, C2.2, J1.1, J2.1, U1.19, U1.25
INT: J2.5, R4.2, U1.24
PU_SCL: JP1.3, R2.2
PU_SDA: JP1.1, R1.2
ROW0: SW1.2, SW2.2, SW3.2, SW13.2, SW14.2, SW15.2, U1.8
ROW1: SW4.2, SW5.2, SW6.2, SW16.2, SW17.2, SW18.2, U1.7
ROW2: SW7.2, SW8.2, SW9.2, SW19.2, SW20.2, SW21.2, U1.6
ROW3: SW10.2, SW11.2, SW12.2, SW22.2, SW23.2, SW24.2, U1.5
RST: J2.6, R3.2, U1.20
SCL: J1.4, J2.4, R2.1, U1.23
SDA: J1.3, J2.3, R1.1, U1.22

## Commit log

2026-10-08 tpu keypad added
    [t9kb_mat.scad, t9kb_mat_body.stl, t9kb_mat_legends.stl]
2026-10-08 case added
    [t9kb_case.scad, t9kb_case_lid.stl, t9kb_case_top.stl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]
2026-10-30 pcb v0.3: updated layout, gerbers and step
2026-10-30 case updated for the pla keycaps
2026-10-30 experimental phone case for the 2.4in spi screen
2026-10-30 build scripts for stl export and slicing
2026-11-01 phone case moved to its own repo, t9kb_phone
2026-11-01 keys: fix stale case MAT comment
